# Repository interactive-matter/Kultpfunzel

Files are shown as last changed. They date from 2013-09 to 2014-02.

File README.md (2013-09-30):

Kultpfunzel
===========

The Customisable Smart Torch
----------------------------

The Kultpfunzel is an Arduino-powered LED torch,
designed to retrofit into a Swiss Army torch enclosure.

The board is Arduino compatible. 

Get the full documentation and show off your hacks at http://kultpfunzel.ch/die-kultpfunzel

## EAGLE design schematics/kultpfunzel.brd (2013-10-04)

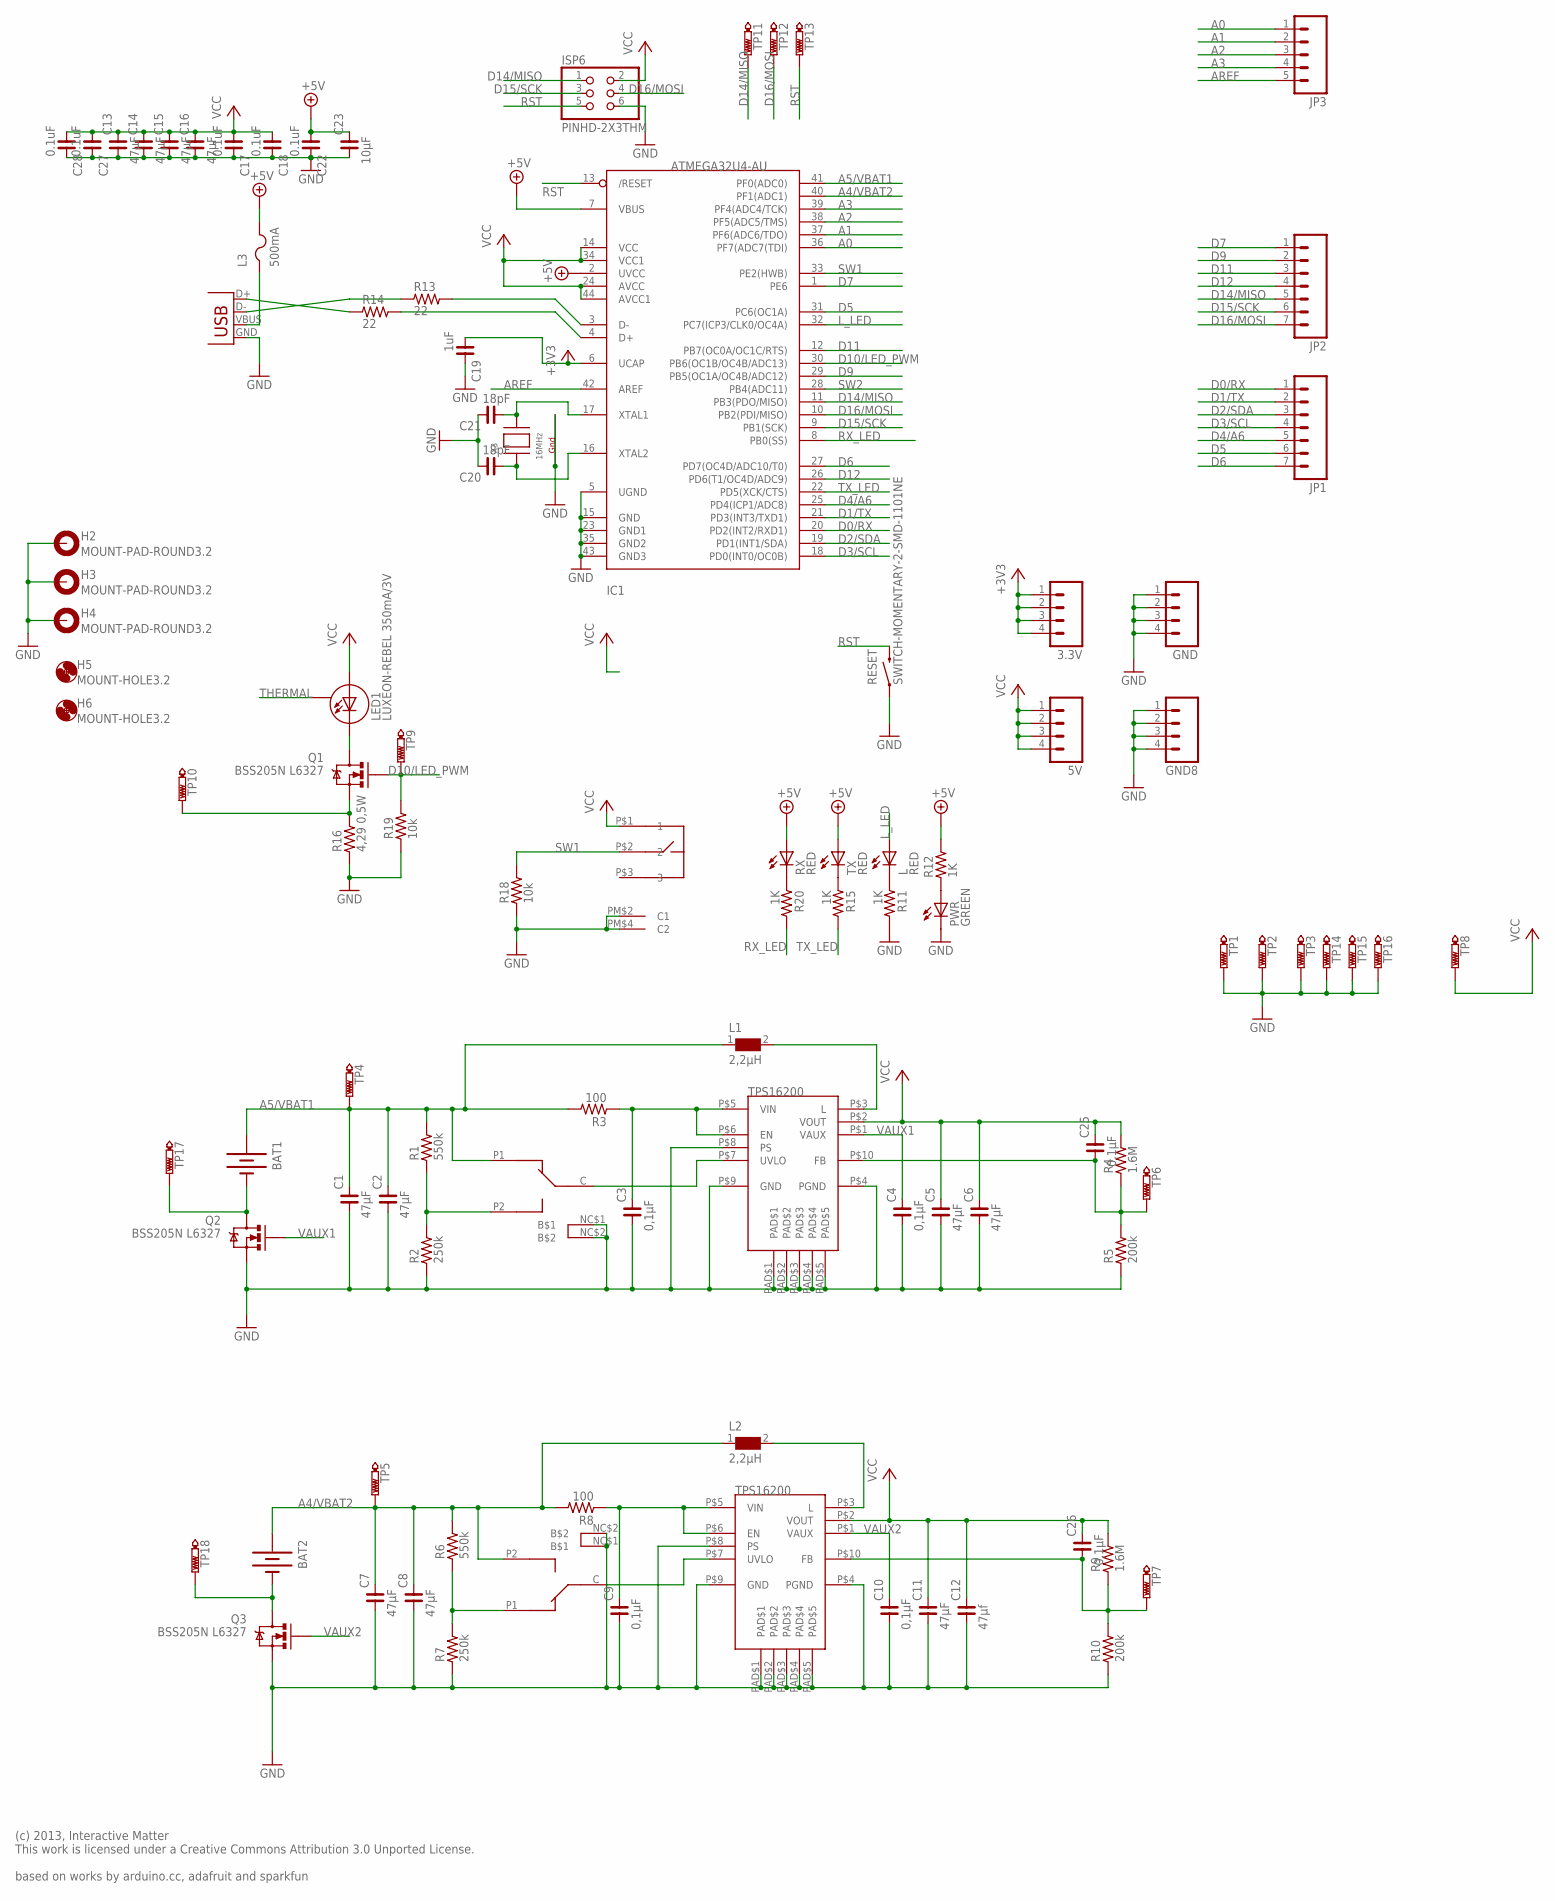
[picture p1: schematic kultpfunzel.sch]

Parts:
3.3V, 5V: M04PTH; 1X04
BAT1, BAT2: BATTERYAA; BATTERY-AA
C1, C2, C7, C8, C13, C14, C15, C16: 47µF; C1206
C3, C4, C9, C10: 0,1µF; C0402
C5, C6, C11: 47µF; C0805
C12: 47µf; C0805
C17, C18, C27, C28: 0.1uF; C0402
C19: 1uF; C0603
C20, C21: 18pF; C0402
C22: 0.1uF; C0603
C23: 10µF; C1206
C25, C26: 0,1µF; C0603
GND, GND8: M04PTH; 1X04
H2, H3, H4: MOUNT-PAD-ROUND3.2; 3,2-PAD
H5, H6: MOUNT-HOLE3.2; 3,2
IC1: ATMEGA32U4-AU; TQFP44
IC2, IC3: TPS61200DRCT; 10SON
ISP6: PINHD-2X3THM; ISP6
JP1, JP2: M07; 1X07
JP3: M05PTH; 1X05
L: RED; CHIPLED_0603
L1, L2: 2,2µH; WE-PD2_M/MS
L3: 500mA; R1206
LED1: LUXEON-REBEL 350mA/3V; LUXEON-REBEL
PWR: GREEN; CHIPLED_0603
Q1, Q2, Q3: BSS205N L6327; SOT23-3
R1, R6: 550k; R0603
R2, R7: 250k; R0603
R3, R8: 100; R0603
R4, R9: 1.6M; R0603
R5, R10: 200k; R0603
R11, R12, R15, R20: 1K; R0603
R13, R14: 22; R0603
R16: 4,29 0,5W; R1210
R18, R19: 10k; R0603
RESET: SWITCH-MOMENTARY-2-SMD-1101NE; TACTILE-SWITCH-1101NE
RX: RED; CHIPLED_0603
SW: TL4105AF
SW1, SW2: SMDSWITCHAYZ0102; SMDSWITCH
TP1, TP2, TP3, TP4, TP5, TP6, TP7, TP8, TP9, TP10, TP11, TP12, TP13, TP14, TP15, TP16, TP17, TP18: PTR1B1,27; B1,27
TX: RED; CHIPLED_0603
USB: USB; USB-MINIB-VERT
X3: 16MHz; NX3225

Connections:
+3V3: 3.3V.1, 3.3V.2, 3.3V.3, 3.3V.4, C19.1, IC1.6 (UCAP)
+5V: C22.1, C23.2, IC1.2 (UVCC), IC1.7 (VBUS), L3.2, R12.2, RX.A, TX.A
A0: IC1.36 (PF7(ADC7(TDI)), JP3.1
A1: IC1.37 (PF6(ADC6/TDO)), JP3.2
A2: IC1.38 (PF5(ADC5/TMS)), JP3.3
A3: IC1.39 (PF4(ADC4/TCK)), JP3.4
A4/VBAT2: BAT2.PWR@1 (+), C7.2, C8.2, IC1.40 (PF1(ADC1)), L2.1, R6.2, R8.2, SW1.P2, TP5.TP
A5/VBAT1: BAT1.PWR@1 (+), C1.2, C2.2, IC1.41 (PF0(ADC0)), L1.1, R1.2, R3.2, SW2.P1, TP4.TP
AREF: IC1.42 (AREF), JP3.5
D0/RX: IC1.20 (PD2(INT2/RXD1)), JP1.1
D1/TX: IC1.21 (PD3(INT3/TXD1)), JP1.2
D2/SDA: IC1.19 (PD1(INT1/SDA)), JP1.3
D3/SCL: IC1.18 (PD0(INT0/OC0B)), JP1.4
D4/A6: IC1.25 (PD4(ICP1/ADC8)), JP1.5
D5: IC1.31 (PC6(OC1A)), JP1.6
D6: IC1.27 (PD7(OC4D/ADC10/T0)), JP1.7
D7: IC1.1 (PE6), JP2.1
D9: IC1.29 (PB5(OC1A/OC4B/ADC12)), JP2.2
D10/LED_PWM: IC1.30 (PB6(OC1B/OC4B/ADC13)), Q1.1 (G), R19.2, TP9.TP
D11: IC1.12 (PB7(OC0A/OC1C/RTS)), JP2.3
D12: IC1.26 (PD6(T1/OC4D/ADC9)), JP2.4
D14/MISO: IC1.11 (PB3(PDO/MISO)), ISP6.1, JP2.5, TP11.TP
D15/SCK: IC1.9 (PB1(SCK)), ISP6.3, JP2.6
D16/MOSI: IC1.10 (PB2(PDI/MISO)), ISP6.4, JP2.7, TP12.TP
GND: C1.1, C2.1, C3.1, C4.1, C5.1, C6.1, C7.1, C8.1, C9.1, C10.1, C11.1, C12.1, C13.1, C14.1, C15.1, C16.1, C17.2, C18.2, C19.2, C20.2, C21.2, C22.2, C23.1, C27.2, C28.2, GND.1, GND.2, GND.3, GND.4, GND8.1, GND8.2, GND8.3, GND8.4, H2.B3,2, H3.B3,2, H4.B3,2, IC1.5 (UGND), IC1.15 (GND), IC1.23 (GND1), IC1.35 (GND2), IC1.43 (GND3), IC2.P$4 (PGND), IC2.P$8 (PS), IC2.P$9 (GND), IC2.PAD$1, IC2.PAD$2, IC2.PAD$3, IC2.PAD$4, IC2.PAD$5, IC3.P$4 (PGND), IC3.P$8 (PS), IC3.P$9 (GND), IC3.PAD$1, IC3.PAD$2, IC3.PAD$3, IC3.PAD$4, IC3.PAD$5, ISP6.6, PWR.C, Q2.2 (S), Q3.2 (S), R2.1, R5.1, R7.1, R10.1, R11.2, R16.1, R18.1, R19.1, RESET.P$1 (1), SW.PM$2 (C1), SW.PM$4 (C2), SW1.NC$1, SW1.NC$2, SW2.NC$1, SW2.NC$2, TP1.TP, TP2.TP, TP3.TP, TP14.TP, TP15.TP, TP16.TP, USB.GND, X3.2 (G2), X3.4 (G1)
L_LED: IC1.32 (PC7(ICP3/CLK0/OC4A)), L.A
unnamed: PWR.A, R12.1
unnamed: R14.1, USB.D+
unnamed: IC1.3 (D-), R13.2
unnamed: IC1.4 (D+), R14.2
unnamed: R13.1, USB.D-
unnamed: LED1.CATHODE (C), Q1.3 (D)
unnamed: IC2.P$3 (L), L1.2
unnamed: C21.1, IC1.17 (XTAL1), X3.3 (X2)
unnamed: C20.1, IC1.16 (XTAL2), X3.1 (X1)
unnamed: L.C, R11.1
unnamed: R1.1, R2.2, SW2.P2
unnamed: IC2.P$7 (UVLO), SW2.C
unnamed: Q1.2 (S), R16.2, TP10.TP
unnamed: C25.1, IC2.P$10 (FB), R4.1, R5.2, TP6.TP
unnamed: BAT1.GND@1 (-), Q2.3 (D), TP17.TP
unnamed: BAT2.GND@1 (-), Q3.3 (D), TP18.TP
unnamed: R15.1, TX.C
unnamed: R20.1, RX.C
unnamed: R6.1, R7.2, SW1.P1
unnamed: IC3.P$7 (UVLO), SW1.C
unnamed: IC3.P$3 (L), L2.2
unnamed: C26.1, IC3.P$10 (FB), R9.1, R10.2, TP7.TP
RST: IC1.13 (/RESET), ISP6.5, RESET.P$2 (2), TP13.TP
RX_LED: IC1.8 (PB0(SS)), R20.2
SW1: IC1.33 (PE2(HWB)), R18.2, SW.P$2 (2)
SW2: IC1.28 (PB4(ADC11))
THERMAL: LED1.P$3 (S)
TX_LED: IC1.22 (PD5(XCK/CTS)), R15.2
VAUX1: C4.2, IC2.P$1 (VAUX), Q2.1 (G)
VAUX2: C10.2, IC3.P$1 (VAUX), Q3.1 (G)
VBUS: L3.1, USB.VBUS
VCC: 5V.1, 5V.2, 5V.3, 5V.4, C5.2, C6.2, C11.2, C12.2, C13.2, C14.2, C15.2, C16.2, C17.1, C18.1, C25.2, C26.2, C27.1, C28.1, IC1.14 (VCC), IC1.24 (AVCC), IC1.34 (VCC1), IC1.44 (AVCC1), IC2.P$2 (VOUT), IC3.P$2 (VOUT), ISP6.2, LED1.ANODE (A), R4.2, R9.2, SW.P$1 (1), TP8.TP
VI1: C3.2, IC2.P$5 (VIN), IC2.P$6 (EN), R3.1
VI2: C9.2, IC3.P$5 (VIN), IC3.P$6 (EN), R8.1

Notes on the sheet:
(c) 2013, Interactive Matter This work is licensed under a Creative Commons Attribution 3.0 Unported License. based on works by arduino.cc, adafruit and sparkfun

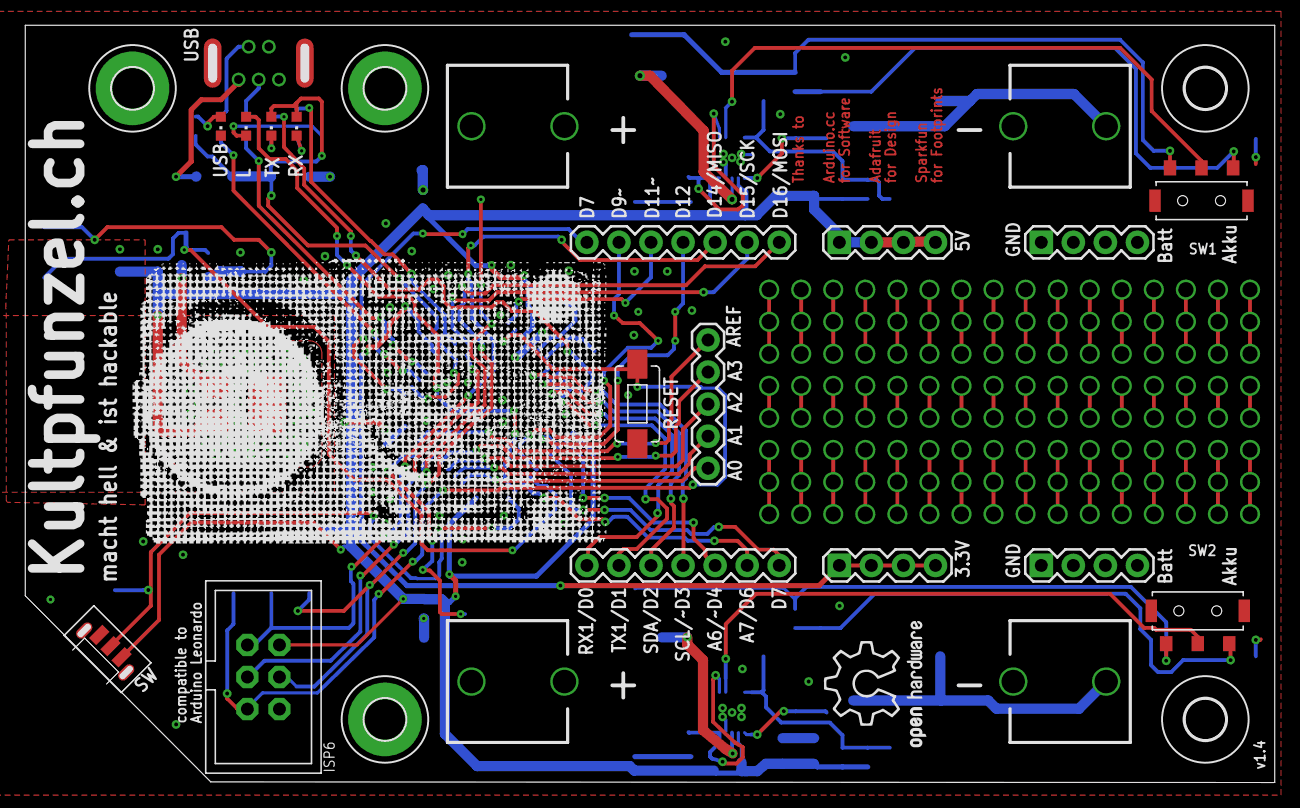
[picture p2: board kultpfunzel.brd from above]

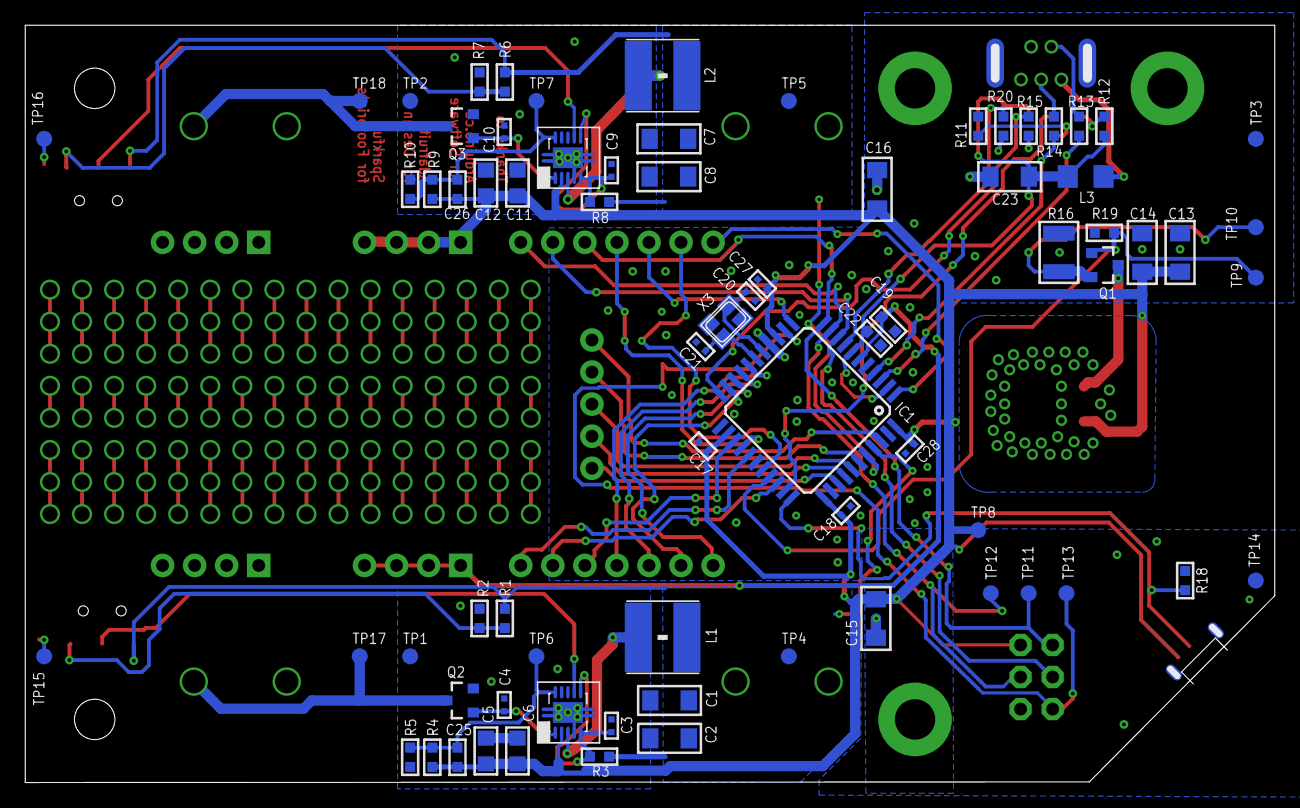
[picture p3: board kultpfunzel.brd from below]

Board: 2 copper layers, 99.0 x 60.0 mm, 101 parts (74 on the bottom side), 58 nets.

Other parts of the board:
U$1: LOGO
U$2: OSHW_LOGO_10MM

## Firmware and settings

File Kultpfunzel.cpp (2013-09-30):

/*
The MIT License (MIT)

Copyright (c) 2013, Interactive Matter, Marcus Nowotny

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
*/
#include "Kultpfunzel.h"

#define LAMP_PIN 10
#define SWITCH_PIN 8

#define ANALOG_PIN_BATTERY_RIGHT 5
#define ANALOG_PIN_BATTERY_LEFT 4

#define ENABLE_OC4B_A (_BV(COM4B1) | _BV(PWM4B))
#define DISABLE_OC4B_A (_BV(PWM4B))
#define ENABLE_OC4B_B (_BV(CS40))
#define DISABLE_OC4B_B (0)

byte last_usb_frame  = 0xff;
boolean usb_communication_active = false;

 Kultpfunzel::Kultpfunzel() {
  //disable the watchdog
  MCUSR = 0;
  wdt_disable();
  //initialize the watchdog
  cli(); //it is best to not get disturbed by interrupts
  //reset the watchdog timer
  wdt_reset();
  //enable the watchdog for writing
  WDTCSR |= _BV(WDCE) | _BV(WDE);
  WDTCSR = _BV(WDCE) | _BV(WDP2) | _BV(WDIE); //enable the prescaler change, enable the interrupt, 0,25s checking interval
  //enalbe interrupts again
  sei();

  //set the switch pins as input
  //switch 1 is PE2 which is normally not usable
  DDRE |= _BV(2);
  PORTE &= ~(_BV(2));
  //the lamp is output
  pinMode(LAMP_PIN,OUTPUT);
  digitalWrite(LAMP_PIN,0);
  //we want to toggle OCR1A & 16 bit fast PWM (WGM13 |WGM12 | WGM 11)
  //fastest mode possible only CS10
  TCCR4D = 0;
  TCCR4A = DISABLE_OC4B_A;
  TCCR4B = DISABLE_OC4B_B;
  //Calculate the gamma corrected brightness values
  initializeLightLevels();
  //we want to count to the highest number
  TC4H = light_levels[254] >>8;
  OCR4C = (unsigned char)light_levels[254];
}

void Kultpfunzel::setLightLevel(unsigned char level) {
  this->level=level;
  //if it is off completely switch it off
  if (level==0) {
    //Disable the OC3A
    TCCR4A = DISABLE_OC4B_A;
    TCCR4B = DISABLE_OC4B_B;
  } 
  else{
    unsigned int light_level = light_levels[level-1];
    TCCR4E |= _BV(TLOCK4);
    //enable TCC3A
    TCCR4A = ENABLE_OC4B_A;
    TCCR4B = ENABLE_OC4B_B;
    TC4H = light_level >>8;
    OCR4B = (unsigned char)(light_level & 0xFF);
    TCCR4E &= ~(_BV(TLOCK4));
  }
}

boolean Kultpfunzel::isSwitch() {
  return PINE & _BV(2);
}

float Kultpfunzel::getVoltageBatteryRight() {
  return getVoltageBattery(ANALOG_PIN_BATTERY_RIGHT);
}

float Kultpfunzel::getVoltageBatteryLeft() {
  return getVoltageBattery(ANALOG_PIN_BATTERY_LEFT);
}

float Kultpfunzel::getVoltageBattery(char battery_port) {
  //set the analog reference to 2.56V for the batteries
  analogReference(INTERNAL);
  int battery_raw = analogRead(battery_port);
  float result = (2.56*battery_raw)/1024.0;
  //set the analog reference back to default
  analogReference(DEFAULT);
  return result;
}

void Kultpfunzel::sleep() {
  //only sleep if we are not connected to usb
  //TODO better than (UDINT & _BV(SUSPI)) &&  ?
  if (!usb_communication_active && level==0) {
    sei();
    //power_adc_disable();
    //power_twi_disable();
    sleep_enable();
    Serial.flush();
    //clear the suspi
    //UDINT &= ~(_BV(SUSPI));
    //disable the leds
    set_sleep_mode(SLEEP_MODE_PWR_DOWN);
    //TODO why doen't it work??
    sleep_cpu();
    sleep_disable();
    //power_adc_enable();
    //power_twi_enable();
    sei();
  }
}

ISR(WDT_vect) {
  byte frame = UDFNUML;
  if (frame != last_usb_frame) {
    usb_communication_active=true;
  } else {
    usb_communication_active=false;
  }
  last_usb_frame=frame;
  sleep_disable();
}

void Kultpfunzel::initializeLightLevels() {
  const double gamma_factor = 2.2;
  const double correction_factor = 1023.0/pow(254.0,gamma_factor);
  //we can test for 0 since we will get an overflow anyway
  for (unsigned char brightness=1;brightness<255;brightness++) {
    double correctedLevel=pow((double)brightness,gamma_factor)*correction_factor;
    light_levels[brightness]=(unsigned int)correctedLevel;
  }
  light_levels[0]=0;
}

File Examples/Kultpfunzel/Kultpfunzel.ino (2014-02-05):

/*
The MIT License (MIT)
 
 Copyright (c) 2013, Interactive Matter, Marcus Nowotny
 
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
 */
#include <Metro.h>
#include <Kultpfunzel.h>
#include <avr/power.h>

//this metro will check the swith every 50ms
Metro pinMetro = Metro(50);
//and this metro will give the battery voltage every minute 
Metro batteryMetro = Metro(60000ul);
//and every 5 ms we will check if the light level has to change
Metro lightMetro = Metro(5);

//the current level of the lamp light
unsigned char current_light_level=0;
//the target level of the lamp ligth - the lamp will fade from current totarget
unsigned char target_light_level=0;
//a quick switch to prevent the lamp from falling asleep
boolean stay_on = false;

//the pfunzel
Kultpfunzel pfunzel;

void setup() {
  //start the serial port
  Serial.begin(9600);
  //and display some nice welcome message
  Serial.println("This is the Kultpfunzel");
  //we do not need the PWI
  power_twi_disable();
}

void loop() {
  //check if we have to check the input switch
  if (pinMetro.check()) {
    //if the switch is set we go to full brightness
    if (pfunzel.isSwitch()) {
      setLampBrightness(255);
    } 
    else {
      //else we switch off thelight
      setLampBrightness(0);
    }
  }
  //check if we have to change the light level
  checkLamp();
  //if it is time to check the battery we will have to do so
  if (batteryMetro.check()) {
    //read an output the battery status
    Serial.println("Battery Status:");
    //the battery voltage is given as convenient floating point given directly the voltage
    float batteryLeft = pfunzel.getVoltageBatteryLeft();
    float batteryRight = pfunzel.getVoltageBatteryRight();
    Serial.print("Battery left: ");
    Serial.println(batteryLeft);
    Serial.print("Battery right: ");
    Serial.println(batteryRight);
    Serial.println();
  }
  if (!stay_on && target_light_level==0 && current_light_level==0) {
    //if we do not output any light we can go asleep
    pfunzel.sleep();
    //we need a short delay in order to ensure that 
    //the pinMetro can catch up eventually
    delay(10);
  }
}

//if we want to set the brigthness we adjust the target - so that we can slowly fade there
void setLampBrightness(unsigned char level) {
  target_light_level=level;
}

//check if we have to adjust the brightness
void checkLamp() {
  //which can only occur in certain intervals and if the target is different from the current level
  if (lightMetro.check() && (target_light_level!=current_light_level)) {
    //if the current level is below the target level
    if (target_light_level>current_light_level) {
      //increase it
      current_light_level++;
    } 
    else {
      //if not decrease it
      current_light_level--;
    }
    //finally tell the pfunzel to go to that level
    pfunzel.setLightLevel(current_light_level);
  }
}

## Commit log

2013-09-30 of course I got this wrong …
2013-10-04 adding the schematics
    [kultpfunzel.brd, kultpfunzel.sch]
2014-02-05 bugfix: pinMetro without boolean argument
    [Kultpfunzel.ino]
